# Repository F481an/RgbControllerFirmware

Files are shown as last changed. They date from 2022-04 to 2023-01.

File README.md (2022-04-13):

The Set and respons Topics can be set with the defines in the defiens.h File

```c++
#define statusTopic "bedroom/UnderBedLight/light/set"
#define BrightnessTopic "bedroom/UnderBedLight/brightness/set"
#define rgbTopic "bedroom/UnderBedLight/rgb/set"

#define statusResponseTopic "bedroom/UnderBedLight/light/status"
#define BrightnessResponseTopic "bedroom/UnderBedLight/brightness/status"
#define rgbResponseTopic "bedroom/UnderBedLight/rgb/status"
```

This is a working example for the configguration in HomeAssistant
```c++
light:
  - platform: mqtt
    name: "UnderBedLight"
    command_topic: "bedroom/UnderBedLight/light/set"
    brightness_command_topic: "bedroom/UnderBedLight/brightness/set"
    rgb_command_topic: "bedroom/UnderBedLight/rgb/set"
    state_topic: "bedroom/UnderBedLight/light/status"
    brightness_state_topic: "bedroom/UnderBedLight/brightness/status"
    rgb_state_topic: "bedroom/UnderBedLight/rgb/status"
    payload_on: "ON"
    payload_off: "OFF"
    optimistic: false
```

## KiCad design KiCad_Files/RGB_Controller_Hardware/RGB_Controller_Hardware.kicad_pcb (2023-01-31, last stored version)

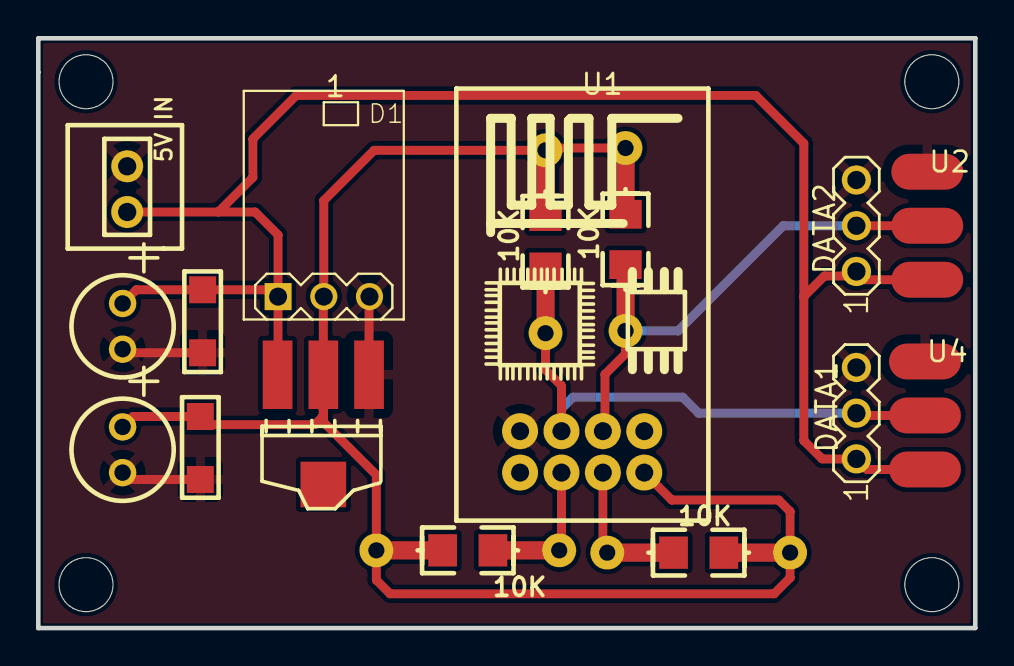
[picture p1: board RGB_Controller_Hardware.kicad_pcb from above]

Board: 2 copper layers, 52.1 x 32.8 mm, 16 parts (0 on the bottom side), 7 nets.

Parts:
1: D1; REG-AMS1117-3P
C2, C3: CAPACITOR-SMD-0.1uF; CAPACITOR-SMD
DATA1, DATA2: 1; 3PIN-HEADER
P1: 5V IN
R1, R2, R3, R4: 10K; AXIAL-0.4 10K
U1: ESP8266 MINI; ESP8266
U2, U4: 3Pin-Neopixel; 3PIN-10MM-LED-STRIP
U3: AMS1117
U7, U9: +; CAPACITOR_I

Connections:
3V3: 1.2, C3.2, R1.2, R2.2, R3.2, R4.2, U1.8, U3.2, U7.1
+5V: 1.1, C2.1, DATA1.1, DATA2.1, P1.1, U2.3, U3.3, U4.3, U9.1
GND: 1.3, C2.2, C3.1, DATA1.3, DATA2.3, P1.2, U1.1, U2.1, U3.1, U4.1, U7.2, U9.2
LED_DATA_1: DATA1.2, R1.1, U1.2, U4.2
LED_DATA_2: DATA2.2, R2.1, U1.3, U2.2
U1_6: R3.1, U1.6
U1_7: R4.1, U1.7

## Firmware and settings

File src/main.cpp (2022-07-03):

#include <Arduino.h>
#include <EEPROM.h>
#include <ArduinoOTA.h>
#include <RestHandler.h>
#include <MqttHandler.h>

#define RedAddr 0
#define GreenAddr 1
#define BlueAddr 2
#define BrightnessAddr 3
#define StateAddr 4

void handleEEprom()
{
    if (Strip.getUpdated())
    {
        EEPROM.write(RedAddr, Strip.getRed());
        EEPROM.write(GreenAddr, Strip.getGreen());
        EEPROM.write(BlueAddr, Strip.getBlue());
        EEPROM.write(BrightnessAddr, Strip.getBrightness());
        EEPROM.write(StateAddr, Strip.getState());
        EEPROM.commit();
        Strip.setUpdated(false);
    }
}

void publischCurrantState() {}

void setup()
{
    ArduinoOTA.begin();
    Serial.begin(9600);
    EEPROM.begin(12);
    connectToWiFi();
    setup_routing();
    if (!connectToMqttServer())
    {
        while (true)
        {
            ArduinoOTA.handle();
        }
    }

    byte red = EEPROM.read(RedAddr);
    byte green = EEPROM.read(GreenAddr);
    byte blue = EEPROM.read(BlueAddr);
    byte brightness = EEPROM.read(BrightnessAddr);
    byte state = EEPROM.read(StateAddr);

    Strip.setColorFill(red, green, blue);
    Strip.setBrightness(brightness);
    Strip.turnOffOn(state);
}

void loop()
{
    MqttHandle();
    RestHandler();
    handleEEprom();
    ArduinoOTA.handle();
}

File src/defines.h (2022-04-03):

#include <Arduino.h>
#include <LEDHandler.h>

#define LED_PIN1 2
#define LED_PIN2 0
#define NUM_LEDS1 36
#define NUM_LEDS2 0
#define LED_TYPE WS2812B

#define statusTopic "bedroom/UnderBedLight/light/set"
#define BrightnessTopic "bedroom/UnderBedLight/brightness/set"
#define rgbTopic "bedroom/UnderBedLight/rgb/set"

#define statusResponseTopic "bedroom/UnderBedLight/light/status"
#define BrightnessResponseTopic "bedroom/UnderBedLight/brightness/status"
#define rgbResponseTopic "bedroom/UnderBedLight/rgb/status"

const char SSID[] = "Klaffenboeck_Wifi";
const char PWD[] = "31862025034211431218";

LedStrip Strip(NUM_LEDS1, LED_PIN1);

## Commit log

2021-12-09 im plemented automatic on of switching
2021-12-12 set fix ip address
    [main.cpp]
2021-12-15 changed ip adresse to upload and chanded amound of leds
2021-12-18 switched to a rgb strip object changed domains for data removed ntp temporaly
2023-01-31 added Kicad Files
    [RGB_Controller_Hardware.kicad_pcb]
2023-03-20 done refactoring
    [RGB_Controller_Hardware.kicad_pcb]
